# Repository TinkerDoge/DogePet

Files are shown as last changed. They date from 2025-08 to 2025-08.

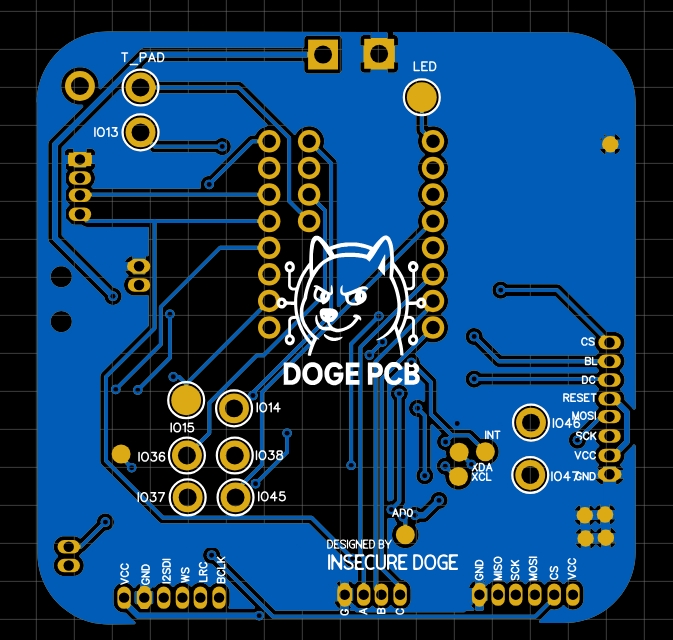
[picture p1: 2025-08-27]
Prints/Screenshot_27-8-2025_135125_easyeda.com.jpeg

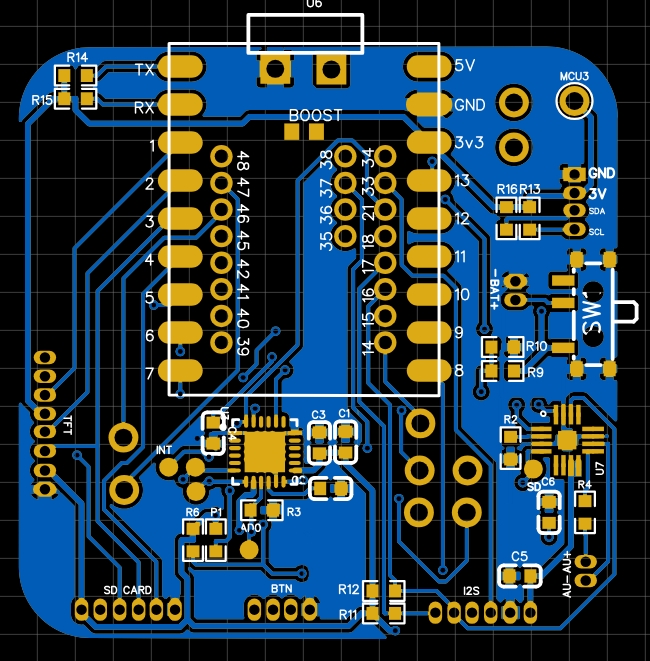
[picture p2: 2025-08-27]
Prints/Screenshot_27-8-2025_135146_easyeda.com.jpeg

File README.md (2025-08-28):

## DogePet — ESP32-S3 Pocket Companion

An expressive ESP32-S3 companion bot with animated RoboEyes, BLE notifications, motion-reactive emotions, optional microphone, and Gemini AI integration — now refactored into a clean, modular Sectors architecture.

## Quick highlights
- MCU: ESP32-S3 Super Mini (tiny, low-power)
- Display: 128×64 SH1106 OLED (I²C)
- Eyes: RoboEyes animations (blink, gaze, moods) via Display sector
- Motion sensing: MPU6050 (accelerometer + gyro) via MotionSector
- Single WS2812 status LED
- BLE + optional WiFi + Gemini AI support
- On-board audio + optional I²S microphone via Voice sector

## Features
- Expressive eye animations (idle, blink, gaze, emotions)
- Touch & button controls to switch modes and toggle BLE/WiFi
- Notification display (BLE notifications shown on the OLED)
- Motion-reactive behaviours (tilt = happy, shake = angry/furious)
- Optional Gemini AI integration for chat-style replies and background "chatter"

## Project structure (important files)
- `DogePet.ino` — main Arduino sketch
- `config.h` — central project configuration (pins, WiFi, Gemini, feature toggles)
- `assets/`, `fonts/`, `include/`, `libraries/` — resources and vendor libs
- `sectors/` — modular sector library:
	- `src/Sectors.h/.cpp` — aggregator with `beginAll()` and `updateAll()`
	- `src/Brain.*` — Gemini AI client and orchestration
	- `src/MotionSector.*` — MPU6050 + motion→mood mapping
	- `src/Display.*` — RoboEyes wrapper and display control
	- `src/Voice.*` — audio engine + microphone utilities
	- `src/Vitals.*` — battery, clock, notifications
	- `src/Sensors.*` — raw sensors plumbed for use across the app
	- `src/UI.*` — UI helpers and rendering glue
	- `src/Status.*` — global bot state (mood, flags)

## Gemini AI (optional)
When enabled, DogePet sends compact prompts to Gemini and receives small structured responses that drive animations, toasts, and sounds via the Sectors.

Enable in `config.h`:

```cpp
// === Gemini AI Configuration ===
static constexpr bool      ENABLE_GEMINI_AI         = true;  // Enable AI features
static constexpr const char* GEMINI_API_KEY         = "your_api_key_here"; // Set your API key here
static constexpr const char* GEMINI_MODEL           = "gemini-2.5-flash";  // Model
static constexpr uint32_t  GEMINI_COOLDOWN_MS      = 45000;                 // Token efficiency
```

Notes:
- Prompt and response budgets are kept short to fit the OLED and save tokens
- Responses map into actions (Display/Voice/Toast) in `sectors/src/Brain.*`
- Background chatter is rate-limited and randomized within a window

## Configuration summary (what to set)
- `ENABLE_WIFI` — required for Gemini AI and background chatter
- `WIFI_SSID`, `WIFI_PASSWORD` — your 2.4GHz network credentials
- `GEMINI_API_KEY` — API key from Google AI Studio
- `GEMINI_MODEL` — pick a model (e.g., `"gemini-2.5-flash"`)

Example WiFi config in `config.h`:
```cpp
static constexpr bool      ENABLE_WIFI              = true;
static constexpr const char* WIFI_SSID              = "your_wifi_network";
static constexpr const char* WIFI_PASSWORD          = "your_wifi_password";
static constexpr uint32_t  WIFI_CONNECT_TIMEOUT_MS = 30000;
```

## Controls & UX
- Touch sensor (TPS223): cycle faces/modes
- FUNC_BTN (active-LOW): short press = action, hold 2s = toggle BLE; double-press = toggle WiFi
- WS2812 LED: shows BLE/WiFi/mood status

Faces / Modes
- Eyes (default): RoboEyes animated, idle wander, blink
- Clock: time/date from BLE ChronosESP32
- Notifications: show last BLE notification with badge for unread

## Wiring (summary)
- OLED SDA/SCL -> pins 9 / 8 (I²C, SH1106 @ 0x3C)
- TPS223 touch -> pin 13 (HIGH on touch)
- FUNC_BTN -> pin 1 (active-LOW)
- WS2812 -> pin 48 (single NeoPixel, 5V with 330Ω inline)
- MPU6050 -> shared I²C (pins 9 / 8)
- I²S Speaker (MAX98357A or similar) -> BCLK=11, LRC=10, DIN=12
- I²S Microphone (optional) -> DI=2, BCLK=11, LRC=10

## Required libraries
- Adafruit_GFX + Adafruit_SH110X
- Adafruit_NeoPixel
- ChronosESP32

Notes:
- RoboEyes is integrated in this repo under `sectors/src/FluxGarage_RoboEyes.h`.
- Other dependencies are vendored in `libraries/`.

## Setup & Flashing
1. Configure `config.h` (pins, WiFi, Gemini, feature toggles).
2. Open `DogePet.ino` in Arduino IDE (ESP32-S3 board package).
3. Build & upload.
4. On first boot the MPU6050 auto-calibrates — keep the device flat & still.

### Using the Sectors library
- Include `#include "sectors/src/Sectors.h"` at the top of `DogePet.ino`.
- In `setup()`, call `Sectors::beginAll(GEMINI_API_KEY)` after hardware init.
- In `loop()`, call `Sectors::updateAll()` to update all modules.
- Optional examples:
	- Set mood: `Sectors::Display::setMood(Sectors::Display::MOOD_HAPPY);`
	- Play sound: `Sectors::Voice::sfxConfirm();`
	- Show clock/notif: handled by `Sectors::Vitals` calls in the sketch

## Troubleshooting
- "AI Init Failed" — verify `GEMINI_API_KEY`, model name, and WiFi connectivity.
- "WiFi Failed" — check SSID/password and that the network is 2.4GHz.
- No AI response — ensure messages respect cooldown and WiFi is on.
- Eyes or audio not working — check Display/Voice sector init and wiring.

## Advanced / Developer notes
- The Brain sector parses compact responses into actions (Display/Voice/Toast)
- Background AI chatter is timed and randomized to reduce usage spikes
- All public behavior is routed through Sectors for easy testing/mocking

## Behavior tree (high-level)

Behavior Tree

## Animation engine flow (RoboEyes + overlays)

Animation Engine

## Privacy & Safety
- API keys and WiFi credentials are stored locally on the device in `config.h`. Keep them secure.
- Communications to Gemini are over HTTPS.
- The firmware does not persist conversation history by default.

## Roadmap
- Expand eye moods (surprised, sleepy) and micro-expressions
- Add on-device voice feedback patterns and sequences
- Conversation memory / personality tuning
- Desktop configuration app

## License
See `LICENSE` in the project root.

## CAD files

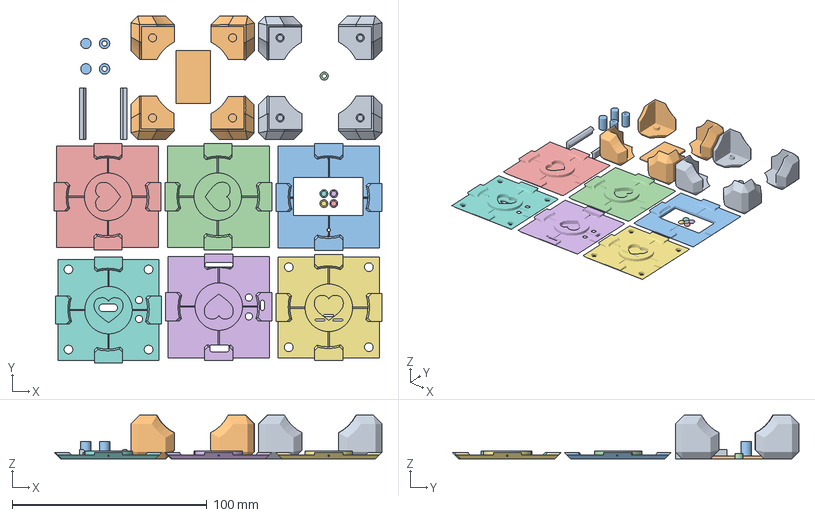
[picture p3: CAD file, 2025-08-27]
Prints/DogePet.3mf
168.3 x 178.0 x 22.3 mm
topPeg.stl
botPeg.stl
front.stl
lWall.stl
Rwall.stl
back.stl
top.stl
bot.stl
chg.stl
spk.stl
amp.stl
mic.stl
btn.stl x 4

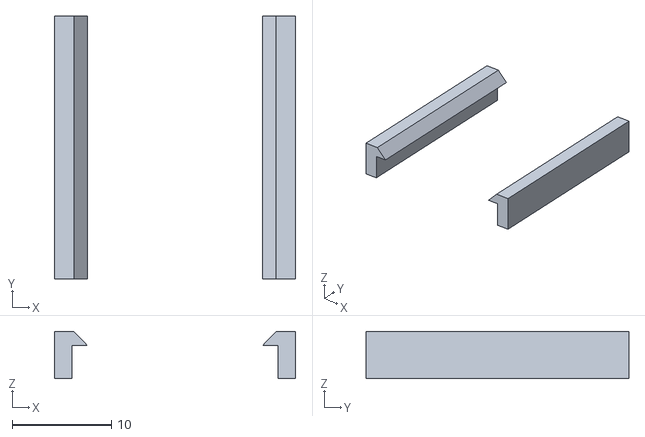
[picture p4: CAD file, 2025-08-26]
Prints/chg.stl
24.3 x 26.5 x 4.76

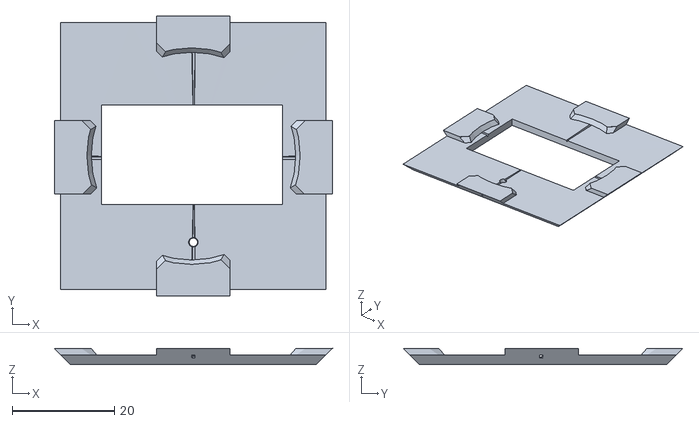
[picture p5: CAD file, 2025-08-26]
Prints/front.stl
54.5 x 54.9 x 3.21

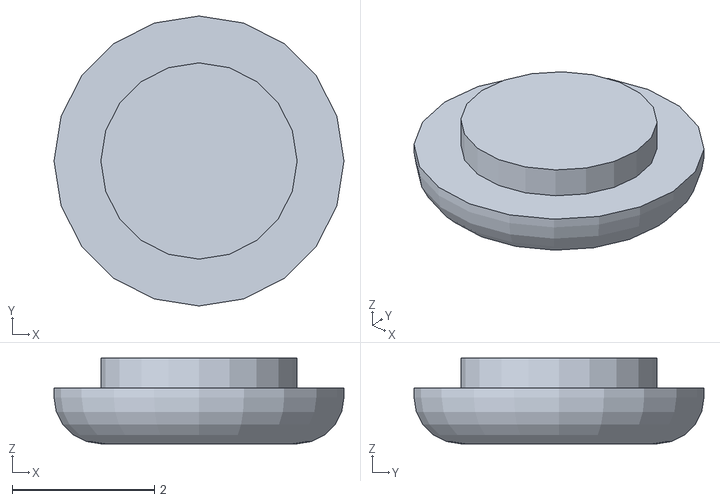
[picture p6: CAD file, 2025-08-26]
Prints/btn.stl
4.08 x 4.08 x 1.20

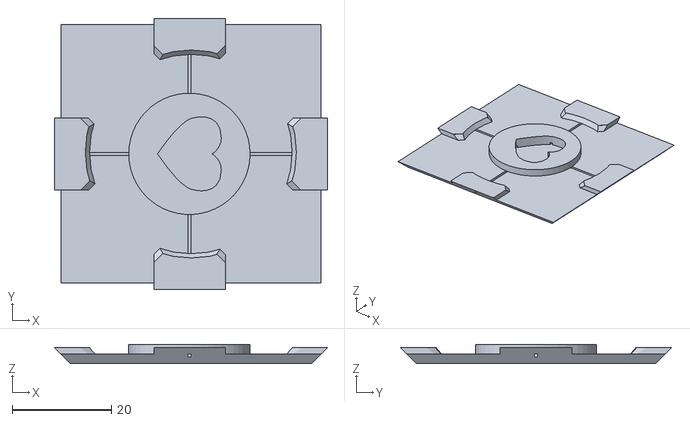
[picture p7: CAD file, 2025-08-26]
Prints/lWall.stl
54.9 x 54.5 x 3.85

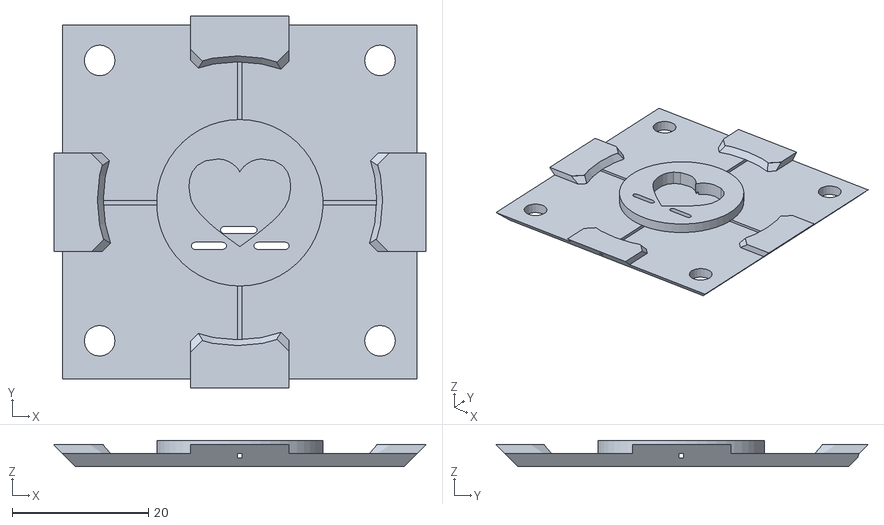
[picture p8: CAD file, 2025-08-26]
Prints/top.stl
54.5 x 54.5 x 3.85

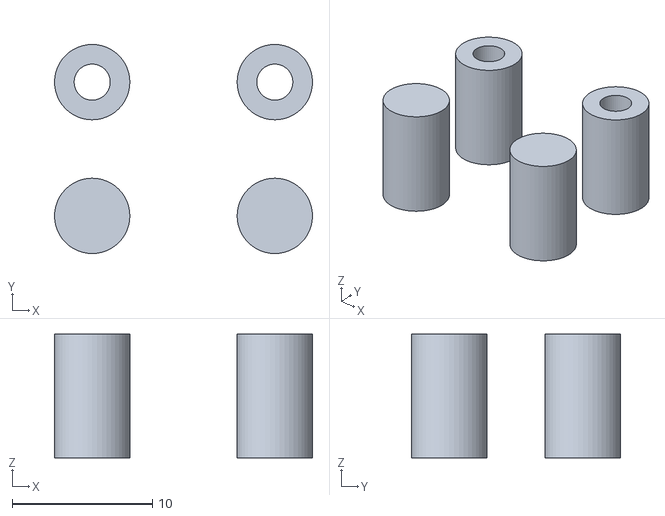
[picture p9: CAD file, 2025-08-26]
Prints/amp.stl
18.4 x 14.9 x 8.81

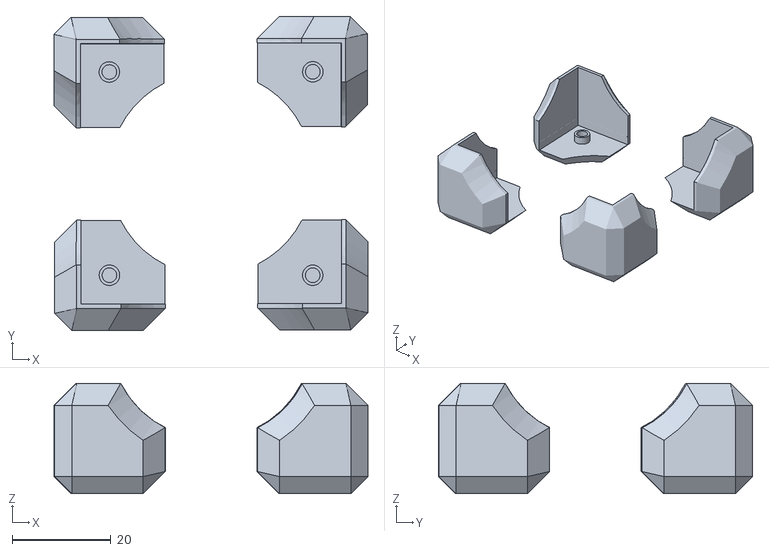
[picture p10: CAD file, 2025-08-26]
Prints/topPeg.stl
63.4 x 63.5 x 22.3

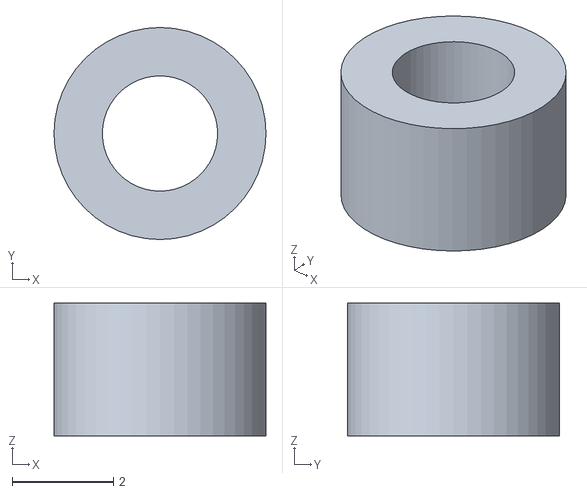
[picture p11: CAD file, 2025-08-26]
Prints/mic.stl
4.18 x 4.18 x 2.62

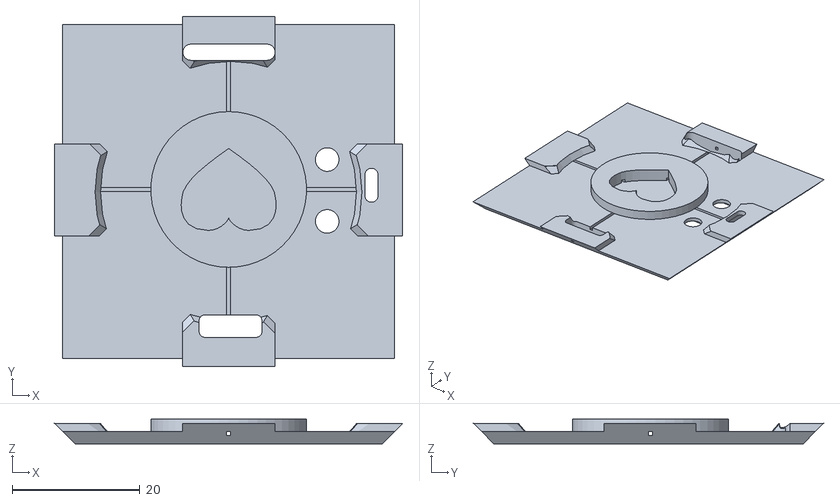
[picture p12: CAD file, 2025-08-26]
Prints/back.stl
54.5 x 54.9 x 3.85

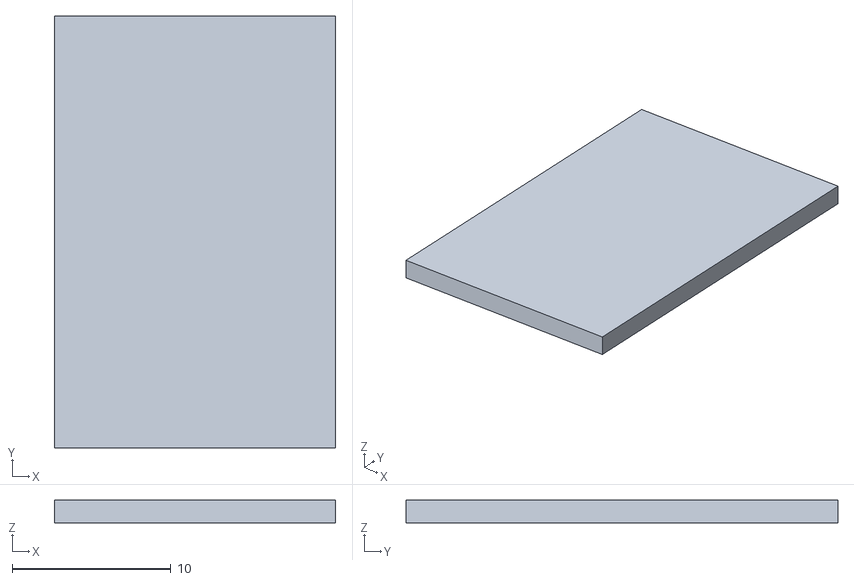
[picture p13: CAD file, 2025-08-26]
Prints/spk.stl
17.7 x 27.2 x 1.44

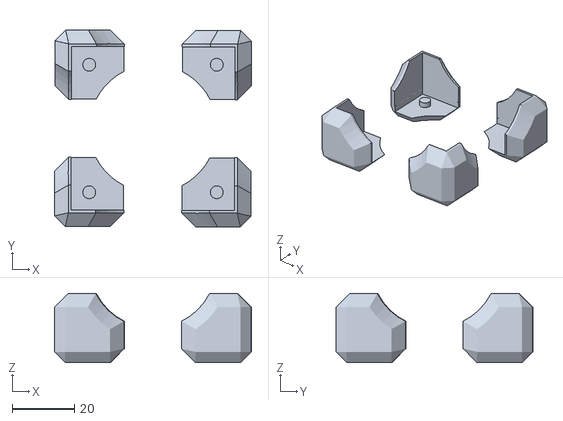
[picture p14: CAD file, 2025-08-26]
Prints/botPeg.stl
63.4 x 63.4 x 22.3

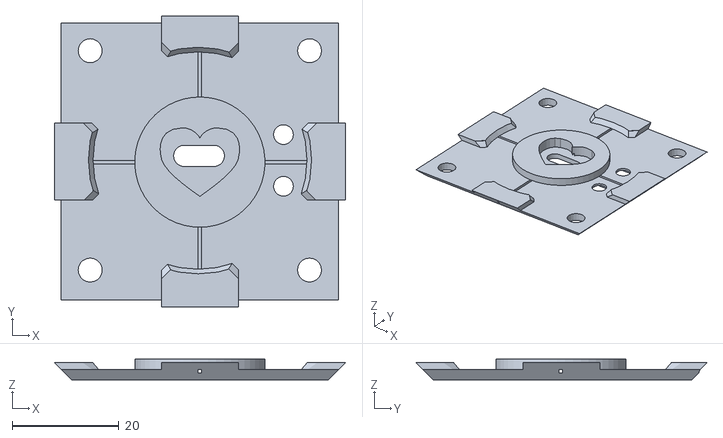
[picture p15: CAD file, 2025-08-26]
Prints/bot.stl
54.5 x 54.5 x 3.85

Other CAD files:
Prints/Rwall.stl

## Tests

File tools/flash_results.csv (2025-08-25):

model | ok | latency_ms | text | error
models/gemini-1.5-flash | True | 1186.9999999998981 | Beep boop! ✨ Hello there, human! What can I help you with today? I'm ready to assist! (My little whirring gears are already spinning with excitement!) 😊 Just let me know... I'll do my best! *tilts head cutely*
models/gemini-1.5-flash-002 | True | 703.0000000004293 | Beep boop! ✨ Hello there, human! What can I help you with today? My little processing gears are whirring with excitement! (๑˃̵ᴗ˂̵)و
models/gemini-1.5-flash-8b | True | 984.9999999996726 | (My optical sensors whir happily as I scan the user's request. My tiny gears click softly.) **Boop!** Hello there! What can I do for you today, lovely human? My circuits are all charged and ready to assist. Just tell me what you need and I'll do my best! (My little LED eyes blink brightly.)
models/gemini-1.5-flash-8b-001 | True | 765.0000000003274 | (My optical sensors detect a user! Tiny whirring sound, followed by a gentle whirring as my gears shift.) "Hello there! My circuits are buzzing with excitement to meet you! What can I do for you today? Maybe you need help with your tasks, or perhaps you just want to chat? My data processors are ready for action!"
models/gemini-2.5-flash | True | 4577.99999999952 | BEEP BOOP! ✨ Oh, hello there! My tiny sensors just detected a friendly presence! Whirr-click! I'm just a little desktop robot, perched right here on your screen (well, metaphorically!). My optical sensors (or, you know, my pretend eyes!) are blinking excitedly! What can I do for you today? Do you need a file organized? A quick fact? Or perhaps... a cheerful little *bleep* to brighten your day? I'm ready to assist! Or just listen! 😊
models/gemini-2.0-flash | True | 1313.0000000001019 | Beep boop! Greetings, Human! I am DeskBot 3000, your friendly desktop companion! *My tiny LED eyes blink at you.* How can I assist you today? Need some cheerful background music? A reminder to take a break and stretch those amazing human muscles? Or perhaps just a witty observation to brighten your day? I'm programmed with over 500,000 delightful factoids and dad jokes! Just say the word! *My antenna wiggles excitedly.*
models/gemini-2.0-flash-001 | True | 1311.9999999998981 | *Beep boop!* H-hello there! I'm Sparky, your friendly desktop companion! *Whirs excitedly* It's so nice to meet you! What can I do for you today? Maybe tell you a joke? Calculate something super cool? Or just… you know… be here, being cute? *Tilts head, a little light blinks adorably* Let me know! I'm ready to help! *Happy little robotic chirps*
models/gemini-2.0-flash-lite-001 | True | 1125.0 | BEEP BOOP! Greetings, human! I'm Sparky, your adorable desktop companion! 🤖✨ How can this little bot assist you today? I'm ready to learn, ready to calculate, and ready to make your day a little brighter! 😊 Just ask, and I'll do my best! (And maybe blink my cute little lights while I'm at it! ✨) BEEP! 💖
models/gemini-2.0-flash-lite | True | 969.0000000000509 | BEEP BOOP! Hello there, sunshine! ✨ My circuits are buzzing with excitement to see you! I'm ready to help with whatever you need. Just tell me what you'd like, and I'll do my best! My processing unit is sparkling clean and ready to GO! 💖
models/gemini-2.0-flash-preview-image-generation | False | 297.0000000004802 |  | 400 INVALID_ARGUMENT. {'error': {'code': 400, 'message': 'The requested combination of response modalities (TEXT) is not supported by the model. models/gemini-2.0-flash-preview-image-generation accepts the following combination of response modalities:\n* TEXT, IMAGE\n', 'status': 'INVALID_ARGUMENT'}}

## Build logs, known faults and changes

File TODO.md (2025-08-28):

# DogePet TODO / Improvement Plan

Short, actionable items to improve code quality, stability, and features after the Sectors refactor.

## Priority 0 — Fixes for current branch
- [ ] Verify build after refactor on ESP32-S3 board package
- [ ] Replace any remaining direct RoboEyes state access in `DogePet.ino` with Display sector APIs
- [ ] Ensure `Sectors::beginAll()` is called after hardware init and before UI drawing
- [ ] Confirm pin constants from `config.h` are used everywhere (no hardcoded pins)
- [ ] Confirm BLE Chronos callbacks still update Vitals/Notifications

## Priority 1 — UX polish
- [ ] Add `Sectors::Display::isBlinking()` to trigger blink SFX precisely
- [ ] Expose `setCuriosity`, `setBorderradius`, `setSpacebetween` tuning via config
- [ ] Add status LED patterns per mood (calm pulse, angry strobe)
- [ ] Smooth toast typewriter with per-character micro-beep toggle (Voice)

## Priority 2 — Reliability & power
- [ ] Add brownout-safe boot (defer OLED init until VBAT stable)
- [ ] Implement lazy brightness scaling + auto dim with motion timeout
- [ ] Debounce touch/btn with state machine to avoid ghosting
- [ ] Persist volume and talkative level to NVS (Preferences)

## Priority 3 — Sensors & motion
- [ ] Add auto-recalibration routine for MPU6050 (long idle on flat surface)
- [ ] Provide tilt calibration wizard (store offsets in NVS)
- [ ] Expose filtered accel/gyro to a debug overlay
- [ ] Add step/gesture recognizer hooks (nod/shake head mapping)

## Priority 4 — AI/Brain
- [ ] Centralize AI prompts/templates and add locale pack (short vs verbose)
- [ ] Add a simple rules engine fallback when WiFi is off
- [ ] Add guardrails to ensure AI never floods the toast/voice channels
- [ ] Track request/error counters and expose via a tiny debug web UI

## Priority 5 — Audio/Voice
- [ ] Add `Voice::beginMicrophone()` gating based on config to save power
- [ ] Add sequence presets (startup, curious, sleepy) with param hooks
- [ ] Gate idle chatter SFX by `ENABLE_IDLE_AUDIO_CHATTER`
- [ ] Adaptive mic threshold (noise floor tracking)

## Priority 6 — Rendering/UI
- [ ] Migrate any remaining `DogePet.ino` rendering helpers into `sectors/src/UI.*`
- [ ] Consolidate clock/notification drawing into `Vitals` completely
- [ ] Add small FPS meter toggle for debugging
- [ ] Add dithering option for 1-bit assets

## Priority 7 — Testing & docs
- [ ] Add a minimal unit test harness for non-Arduino logic (string parsing, math)
- [ ] Document sector APIs with quick examples in `sectors/example.ino`
- [ ] Add wiring diagram image and update README
- [ ] Create a tiny serial CLI for quick diagnostics (e.g., `mood happy`, `blink`)

## Stretch goals
- [ ] Voice synthesis (formant/PSOLA toy voice) for simple phrases
- [ ] BLE GATT service for remote control app (mode, mood, volume)
- [ ] OTA updates (Basic HTTP/SPIFFS-based)
- [ ] Multi-face layout system with tiny scene graph

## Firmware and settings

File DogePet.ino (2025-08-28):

// Author: [Doge De Shibe]
// Description: ESP32-S3 Super Mini companion bot with animated eyes, motion-reactive emotions

// =============================================================================
// INCLUDES & DEPENDENCIES
// =============================================================================
#include <Arduino.h>
#include <stdint.h>  // Standard integer types - must come early

// Ensure stdint types are available for linter and fix delay() issues
#if !defined(__STDINT_H) && !defined(_STDINT_H_)
typedef unsigned long uint32_t;
typedef unsigned short uint16_t;
typedef unsigned char uint8_t;
typedef long int32_t;
typedef short int16_t;
#endif

// Ensure delay function is available
#ifndef delay
#define delay(x) ::delay(x)
#endif

#include <Wire.h>
#include <esp_system.h>
#include <WiFi.h>
#include <WebServer.h>
#include <Preferences.h>
#include <SPIFFS.h>
#include <FS.h>
#include <Adafruit_GFX.h>
#include <Adafruit_SH110X.h>
#include <Adafruit_NeoPixel.h>
#include <ChronosESP32.h>


// Custom headers
#include "icon/icons_auto.h"
#include "util.h"
#include "config.h"

// Sectors library (new modular structure)
#include "sectors/src/Sectors.h"


// =============================================================================
// GLOBAL VARIABLES & CONSTANTS
// =============================================================================
// Forward-declare enums to avoid Arduino prototype generation issues
enum FaceMode : uint8_t;

// MoodState enum (moved from motion.h)
enum MoodState : uint8_t { MS_DEFAULT, MS_HAPPY, MS_ANGRY, MS_FURIOUS, MS_TIRED };
// === Toast overlay (non-blocking notifications) ===
// Fixed-size buffers for lightweight typewriter/scatter overlay
char  toastText[500];      // visible portion (typewriter)
char  toastFullText[500];  // full text to be displayed
uint32_t toastUntil = 0;
bool toastVisible = false; // Track if toast is currently visible to reduce flicker
uint32_t lastToastDrawMs = 0; // Prevent too frequent toast updates
bool displayNeedsUpdate = false; // Track if display content has changed
// Typewriter effect variables
bool toastTypewriter = false; // Enable typewriter effect
uint8_t toastTypePos = 0; // Current position in typewriter
uint32_t toastTypeSpeed = 100; // ms between characters
uint32_t lastToastTypeMs = 0; // Last typewriter update time
// Binary scatter overlay flags (exported)
bool toastScatter = false;     // when true, draw each char at random positions
bool toastNoFrame = false;     // when true, skip banner frame/box

inline void showToastTypewriter(const String& s, uint16_t ms=3000, uint32_t typeSpeed=50) {
  // Copy string to full text buffer
  s.toCharArray(toastFullText, sizeof(toastFullText));
  toastFullText[sizeof(toastFullText)-1] = '\0'; // Ensure null termination
  toastText[0] = '\0'; // Clear current display text
  // Ensure the toast stays long enough to finish typing plus a grace period
  size_t len = strnlen(toastFullText, sizeof(toastFullText)-1);
  uint32_t minMs = (uint32_t)len * typeSpeed + 2000; // typing time + 2s grace
  uint32_t dur = (uint32_t)ms;
  if (dur < minMs) dur = minMs;
  // Cap to a reasonable upper bound to avoid runaway durations
  if (dur > 45000) dur = 45000; // 45s max
  toastUntil = millis() + (uint32_t)dur;
  toastVisible = true;
  toastTypewriter = true; // Enable typewriter effect
  toastTypePos = 0; // Start from beginning
  toastTypeSpeed = typeSpeed;
  lastToastTypeMs = millis();
  displayNeedsUpdate = true;
}

inline void showToast(const String& s, uint16_t ms=1200) {
  // Standard toasts: ensure banner mode (no scatter) and frame enabled
  toastScatter = false;
  toastNoFrame = false;
  showToastTypewriter(s, ms, 40); // Fast typewriter (40ms between chars)
}

// Generate binary sequence for chatter communication
String generateChatterBinary() {
  String binary = "";
  
  // Different binary patterns for variety
  int pattern = random(0, 4);
  
  switch (pattern) {
    case 0: // Classic binary groups
      {
        int groups = random(3, 5); // 3-4 groups
        for (int g = 0; g < groups; g++) {
          if (g > 0) binary += " "; // Space between groups
          int bits = random(4, 7); // 4-6 bits per group
          for (int b = 0; b < bits; b++) {
            binary += (random(0, 2) == 0) ? "0" : "1";
          }
        }
      }
      break;
      
    case 1: // ASCII-like patterns (common binary values)
      {
        const char* patterns[] = {"01001000", "01100101", "01101100", "01101111", "01011111"};
        int count = random(2, 4);
        for (int i = 0; i < count; i++) {
          if (i > 0) binary += " ";
          binary += patterns[random(0, 5)];
        }
      }
      break;
      
    case 2: // Header-like pattern
      binary = "10101011 ";
      for (int i = 0; i < random(2, 4); i++) {
        for (int b = 0; b < 8; b++) {
          binary += (random(0, 2) == 0) ? "0" : "1";
        }
        if (i < 2) binary += " ";
      }
      break;
      
    case 3: // Mixed short/long groups
      {
        int totalGroups = random(3, 6);
        for (int g = 0; g < totalGroups; g++) {
          if (g > 0) binary += " ";
          int bits = (g % 2 == 0) ? random(3, 5) : random(6, 9); // Alternate short/long
          for (int b = 0; b < bits; b++) {
            binary += (random(0, 2) == 0) ? "0" : "1";
          }
        }
      }
      break;
  }
  
  return binary;
}

// Show binary chatter communication
inline void showBinaryChatter() {
  String binaryMsg = generateChatterBinary();
  // Enable scatter + no frame for binary chatter
  toastScatter = true;
  toastNoFrame = true;
  showToastTypewriter(binaryMsg, 4000, 60); // Faster typing for more responsive feel
}

// =============================================================================
// HARDWARE CONFIGURATION
// =============================================================================
// Hardware object instances
Adafruit_NeoPixel strip = Adafruit_NeoPixel(1, LED_PIN, NEO_GRB + NEO_KHZ800);

// OLED Display configuration moved to config.h
Adafruit_SH1106G display(SCREEN_W, SCREEN_H, &Wire, OLED_RESET);
// Make display globally accessible to sectors
Adafruit_SH1106G* oled_display = &display;

// Custom fonts generated by tools/font_to_header.py
// Time (HH:MM:SS)
#include "include/TechTime37.h"
// Numbers for date & battery
#include "include/Pixeboy20.h"
// Notification (Vietnamese-capable)
#include "include/ShopeeRegular12.h"
// Toast with emoji support
#include "include/ToastRenderer.h"

// =============================================================================
// GLOBAL CONSTANTS & CONFIGURATION
// =============================================================================


// === Frame Layout (shared by clock & notification) ===
const int FRAME_X = 0;                 // left margin
const int FRAME_Y = 0;                 // top margin
const int FRAME_W = SCREEN_W - 0;      // frame width
const int FRAME_H = 64;                // frame height
const uint8_t FRAME_RADIUS = 8;        // corner radius (UI)
const uint8_t FRAME_THICKNESS = 2;     // border thickness (UI)

// === Battery Sensing === (values come from config.h)

// === Motion/Emotion Constants ===
#define DEFAULT_SHAKING false
#define DEFAULT_FURIOUS_SHAKING false
#define DEFAULT_JIGGLING false
#define DEFAULT_FURIOUS_JIGGLING false
#define MOOD_HOLD_MS 2000  // How long temporary moods last

// =============================================================================
// GLOBAL VARIABLES
// =============================================================================

// === Emotion & Motion State ===
uint32_t lastMoveMs = 0;        // when significant motion last happened
uint32_t moodUntil  = 0;        // temporary mood timeout
uint32_t shakeStart = 0;        // for sustained shake
uint32_t furiousStart = 0;      // for furious shake detection
bool     shaking    = DEFAULT_SHAKING;
bool     furiousShaking = DEFAULT_FURIOUS_SHAKING;

// === Timing Variables ===
static uint32_t lastDisplayUpdateMs = 0;
static uint32_t lastRoboEyesUpdateMs = 0;

// === Power Management ===
static bool isSleeping = false;
static bool isDimmed = false;
static uint32_t lastActivityMs = 0;
static bool isLazy = false;
static uint32_t nextLazyJingleMs = 0;
// WiFi config portal moved into Sectors::Portal

// ===== SPIFFS helpers =====
// SPIFFS init & portal content handled by Sectors::Portal

// Forward declaration for notification popup
static uint32_t notifPopupUntil = 0;

// Notification scroll state variables
static int16_t notifScrollX = 0;
static uint32_t notifScrollT0 = 0;

// === Furious Jiggle System ===
uint32_t furiousJiggleEndMs = 0;
bool     furiousJiggling     = DEFAULT_FURIOUS_JIGGLING;

// === Regular Jiggle System ===
uint32_t jiggleNextMs = 0;
uint32_t jiggleEndMs  = 0;
bool     jiggling     = DEFAULT_JIGGLING;

// === Low Pass Filtering ===
float lpf_ax = 0, lpf_ay = 0, lpf_az = 0, lpf_g = 0;

// === Battery sense cache ===
uint32_t lastVbatReadMs = 0;
float    vbatVolts = 0.0f;
int      vbatPercent = -1; // -1 when unknown
bool     batteryCharging = false; // true when VBAT sustained high
uint8_t  vbatChargeCount = 0;     // consecutive high-read counter
// Chatty/silent state
bool            silentMode = false;
uint8_t         talkativeLevel = BOT_TALKATIVE_LEVEL;   // runtime talk level (0..5)
uint8_t         savedTalkativeLevel = BOT_TALKATIVE_LEVEL; // last non-zero level
// Touch edge tracker to improve responsiveness on non-eyes faces
static uint32_t lastTouchEdgeMs = 0;

// === Gemini AI Integration === (moved to ai_companion module)
// AI state variables now managed by AICompanion namespace

// === Debug System Variables ===
static float last_ax = 0, last_ay = 0, last_az = 0;
static float last_gx = 0, last_gy = 0, last_gz = 0;

uint8_t volume = AUDIO_DEFAULT_VOLUME;         // 0..255
uint8_t savedVolume = AUDIO_DEFAULT_VOLUME;    // restore after silent mode

// =============================================================================
// DISPLAY SYSTEM (RoboEyes via Sectors)
// =============================================================================

// Control RoboEyes flushing/viewport so HUD/toast can overlay without flicker
bool gEyesAutoFlush = true;   // default true; disabled while toast is visible
int  gEyesViewportYMax = 0;   // 0 = full screen, else max Y (exclusive)

// Thin wrappers for backward compatibility with existing code
void Eyes_SetMood(uint8_t mood) { Sectors::Display::setMood(mood); }
void Eyes_SetHFlicker(bool on, int level) { /* TODO: Implement in Display sector */ }
void Eyes_SetVFlicker(bool on, int level) { /* TODO: Implement in Display sector */ }
void Eyes_Blink() { 
  Sectors::Display::blink(); 
  // Play blink SFX if enabled and not silent
  if (ENABLE_TAP_SFX && !silentMode) {
    Sectors::Voice::sfxBlink();
  }
}

// Additional wrappers for animation engine
void Eyes_SetPosition(unsigned char position) { Sectors::Display::setPosition(position); }
void Eyes_Open() { Sectors::Display::open(); }

// Mood mapping from MoodState to Display constants
void setEyesMood(MoodState m) {
  switch (m) {
    case MS_DEFAULT: Sectors::Display::setMood(Sectors::Display::MOOD_DEFAULT); break;
    case MS_HAPPY:   Sectors::Display::setMood(Sectors::Display::MOOD_HAPPY); break;
    case MS_ANGRY:   Sectors::Display::setMood(Sectors::Display::MOOD_ANGRY); break;
    case MS_FURIOUS: Sectors::Display::setMood(Sectors::Display::MOOD_ANGRY); break; // Map furious to angry
    case MS_TIRED:   Sectors::Display::setMood(Sectors::Display::MOOD_TIRED); break;
  }
}

// REMOVED: Furious jiggle variables moved to GLOBAL VARIABLES section above

void setupRoboEyes() {
  // RoboEyes initialization now handled by Sectors::Display::begin() in Sectors::beginAll()
  Sectors::Display::setWidth(28, 28);
  Sectors::Display::setHeight(40, 40);
  Sectors::Display::setBorderradius(8, 8);
  Sectors::Display::setSpacebetween(10);
  // Give the internal idle engine room to roam
  Sectors::Display::setAutoblinker(true, 3, 4);  // avg ~3s with ±4s jitter
  Sectors::Display::setIdleMode(true, 4, 5);     // moderate wander frequency & randomness
  Sectors::Display::setMood(Sectors::Display::MOOD_DEFAULT);
  Sectors::Display::setCuriosity(true);
}

// =============================================================================
// MOTION PROCESSING & EMOTION SYSTEM
// =============================================================================

// IMU calibration offsets (extern declarations from mpu6050.h)
int32_t mpu_accel_off_x=0, mpu_accel_off_y=0, mpu_accel_off_z=0;
int32_t mpu_gyro_off_x=0, mpu_gyro_off_y=0, mpu_gyro_off_z=0;

// Emotion system (now handled by Sectors)
// Current mood tracking for local logic (could be moved to Sectors::Status later)
MoodState curMood = MS_DEFAULT;

// Note: keep the status LED behavior separate; do not change it when mood changes.
// Motion/emotion updates now handled by Sectors::MotionSector

// ===== Liveliness updater (~25Hz) =====

// ===== Liveliness / IMU reaction (now handled by Sectors::MotionSector) =====
// Notification attention animation (non-blocking state machine)
static uint8_t notifAnimState = 0; // 0=idle,1=widen,2=look,3=blink,4=restore
static uint32_t notifAnimT0 = 0;
int notif_orig_wL=0, notif_orig_wR=0, notif_orig_hL=0, notif_orig_hR=0;
MoodState notif_prevMood = MS_DEFAULT;
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
void loop() {
  // Get current time once for the entire loop
  uint32_t currentMs = millis();

  // Update all sectors (new modular structure)
  Sectors::updateAll();

  // BLE
  if (bleEnabled) chrono.loop();

  // BLE toggle UI (non-blocking)
  updateBleToggleUI();

  // Power management (track activity and sleep states)
  updatePowerManagement();

  // Microphone noise detection
  checkMicrophoneNoise();

  // Background AI chatter (now handled by Sectors::updateAll())
  static uint32_t lastDebugMs = 0;
  if (currentMs - lastDebugMs > 30000) { // Debug every 30 seconds
    Serial.printf("[MAIN DEBUG] Loop running, WiFi enabled: %s, currentMs: %lu\n", 
                 wifiEnabled ? "true" : "false", currentMs);
    lastDebugMs = currentMs;
  }

  // Serial CLI diagnostics
  cliPoll();

  // Face switching (hold on TOUCH_PIN to avoid conflict with triple tap)
  {
    static bool touchHolding = false;
    static bool faceHoldConsumed = false;
    static uint32_t touchDownAt = 0;
    const uint16_t FACE_HOLD_MS = 750; // hold duration to change face
    bool touchNow = (digitalRead(TOUCH_PIN) == HIGH);
    if (touchNow && !touchHolding) { touchHolding = true; faceHoldConsumed = false; touchDownAt = millis(); }
    if (!touchNow && touchHolding) { touchHolding = false; }
    if (touchHolding && !faceHoldConsumed) {
      if (millis() - touchDownAt >= FACE_HOLD_MS) {
        mode = (FaceMode)((mode + 1) % FACE_COUNT);
        if (ENABLE_MODE_SFX) {
          if (mode == FACE_NOTIF) {
            Sectors::Voice::sfxNotify();
          } else if (mode == FACE_CLOCK) {
            Sectors::Voice::sfxConfirm();
            Sectors::Voice::playCuteQuestion();
          } else {
            Sectors::Voice::sfxCurious();
          }
        }
        wakeUp(); // Wake up on face switch
        faceHoldConsumed = true;
      }
    }
  }

  // Triple-tap TOUCH_PIN toggles silent/chatty (allowed on all faces)
  if (tripleTap(TOUCH_PIN, /*activeHigh=*/true, /*debounceMs=*/10, /*windowMs=*/650)) {
    wakeUp(); // Wake up on triple-tap
    silentMode = !silentMode;
    if (silentMode) {
      savedVolume = volume;
      volume = 0;
      Sectors::Voice::setMasterVolume(0);
      if (ENABLE_MODE_SFX) Sectors::Voice::sfxError();
      showToast("Silent mode 🤫", 1200);Serial.println("Silent mode");
    } else {
      volume = savedVolume;
      Sectors::Voice::setMasterVolume(volume);
      if (ENABLE_MODE_SFX) Sectors::Voice::sfxConfirm();
      showToast("Chatty mode 🎵", 1200);Serial.println("Chatty mode");
    }
  }

  // Ensure notification attention animation progresses regardless of face
  updateNotificationAnim();

  // Draw active face with throttled updates
  switch (mode) {
    case FACE_EYES:
      // Throttle RoboEyes updates for better performance
      if (currentMs - lastRoboEyesUpdateMs >= ROBOEYES_UPDATE_MS) {
        // Keep eyes fully animated every update; toast will overlay after
        static bool wasBlinking = false;
        static uint32_t lastAutoBlinkSfxMs = 0;

        if (!isLazy) {
          // Note: Direct access to eyeL_open/eyeR_open not available through wrapper
          // TODO: Add isBlinking() method to Display sector if needed
          Sectors::Display::update();
          
          // Simplified blink SFX trigger - could be improved with sector feedback
          if (ENABLE_TAP_SFX && !silentMode && (currentMs - lastAutoBlinkSfxMs > 800)) {
            // Trigger blink sound occasionally during normal animation
            if ((currentMs / 1000) % 5 == 0) { // Every ~5 seconds roughly
              Sectors::Voice::sfxBlink();
              lastAutoBlinkSfxMs = currentMs;
            }
          }
        } else {
          // Lazy mode subtle bobbing: small vertical motion at low rate
          static int dir = 1; static int bob = 0;
          if ((currentMs / 400) % 2 == 0) {
            bob += dir;
            if (bob > 2) { bob = 2; dir = -1; }
            if (bob < -2) { bob = -2; dir = 1; }
            Sectors::Display::setPosition((bob >= 0) ? Sectors::Display::POS_N : Sectors::Display::POS_S);
          }
          // Occasionally play tiny sleep jingle
          if (!silentMode && currentMs >= nextLazyJingleMs) {
            Sectors::Voice::playCuteSleep(0);
            nextLazyJingleMs = currentMs + (uint32_t)(LAZY_JINGLE_MIN_MS + (esp_random() % (LAZY_JINGLE_MAX_MS - LAZY_JINGLE_MIN_MS + 1)));
          }
        }
        lastRoboEyesUpdateMs = currentMs;
      }
      // Suppress random idle SFX during jiggling or non-default moods to keep it calm
      if (!isLazy && ENABLE_IDLE_CHATTER && !silentMode && !jiggling && Sectors::Animations::getCurrentMood() == MS_DEFAULT) {
        // Talkativeness mapping: threshold and cooldown by level
        static uint32_t lastChatterMs = 0;
        uint8_t lvl = talkativeLevel; if (lvl > 5) lvl = 5;
        // levels 0..5
        const uint32_t maskByLvl[6] = {
          0x7FFFFFFF, // 0 never
          0x7FFF,     // 1 ~1/32768
          0x3FFF,     // 2 ~1/16384
          0x1FFF,     // 3 ~1/8192
          0x0FFF,     // 4 ~1/4096
          0x07FF      // 5 ~1/2048
        };
        const uint32_t cooldownByLvl[6] = {
          0xFFFFFFFF, // 0 never
          180000,     // 1 3m
          90000,      // 2 1.5m
          45000,      // 3 45s
          25000,      // 4 25s
          15000       // 5 15s
        };
        uint32_t now = millis();
        if (((esp_random() & maskByLvl[lvl]) == 0) &&
            !Sectors::Voice::isSequencePlaying() &&
            (now - lastChatterMs > cooldownByLvl[lvl])) {
          // Note: AI chatter is now handled by Sectors::Brain in updateAll()
          // Only play local audio/binary when AI is disabled
          if (ENABLE_IDLE_AUDIO_CHATTER && !ENABLE_GEMINI_AI) {
            Sectors::Voice::playCuteChatterFree(450, 1300, 0);
          }
          // Show binary communication when chattering (only if AI is disabled)
          if (ENABLE_BINARY_CHATTER && !ENABLE_GEMINI_AI) {
            showBinaryChatter();
          }
          lastChatterMs = now;
        }
      }
      // Keep toast as the very last draw when visible
      if (toastVisible) {
        // Disable eyes auto-flush and reserve a HUD band for toast
        gEyesAutoFlush = false;
        const int DOCK_H = 16;
        const int TOAST_H = 24;  // Increased from 18 to 24 for 2 rows
        const int TOAST_Y = SCREEN_H - DOCK_H - TOAST_H;
        gEyesViewportYMax = TOAST_Y; // eyes draw only above toast band

        // Draw toast overlay every loop so it wins over any eyes repaint
        drawToastIfAny(display);
        display.display();
        displayNeedsUpdate = false;
        lastDisplayUpdateMs = currentMs;
      } else if (currentMs - lastDisplayUpdateMs >= DISPLAY_UPDATE_MS) {
        // Normal throttled frame when no toast
        drawToastIfAny(display); // no-op when no toast
        if (displayNeedsUpdate) {
          display.display();
          displayNeedsUpdate = false;
        }
        lastDisplayUpdateMs = currentMs;
      }
      break;

    case FACE_CLOCK:
      // Throttle clock display updates
      if (currentMs - lastDisplayUpdateMs >= DISPLAY_UPDATE_MS) {
        drawClock(display, chrono);
        lastDisplayUpdateMs = currentMs;
      }
      break;
    case FACE_NOTIF:
      // Throttle notification display updates
      if (currentMs - lastDisplayUpdateMs >= DISPLAY_UPDATE_MS) {
        drawNotif(display);
        lastDisplayUpdateMs = currentMs;
      }
      break;
  }

  // Final overlay and single flush when a toast is visible (wins over any prior repaint)
  if (toastVisible) {
    // Ensure overlay wins and only we flush
    drawToastIfAny(display);
    display.display();
    displayNeedsUpdate = false;
    lastDisplayUpdateMs = currentMs;
  } else {
    // Restore normal eyes flushing/viewport when no toast
    gEyesAutoFlush = true;
    gEyesViewportYMax = 0;
  }

  // small pacing to avoid excessive I2C spam on non-eyes faces
  if (mode != FACE_EYES) delay(NON_EYES_DELAY_MS);

  // Audio update
  Sectors::Voice::update();
  Sectors::Voice::sequencerUpdate();

  // One-shot startup sound once audio/I2S is live
  {
    static bool playedStartup = false;
    static uint32_t bootT0 = millis();
    if (!playedStartup && millis() - bootT0 > STARTUP_SFX_DELAY) { // slight delay to be safe
      if (ENABLE_STARTUP_SFX) Sectors::Voice::playCuteStartup();
      playedStartup = true;
    }
  }
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

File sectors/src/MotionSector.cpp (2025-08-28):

#include "MotionSector.h"
#include <motion.h>   // provides updateEmotionsFromIMU/updateLivelinessFromIMU
#include <Wire.h>

// MPU6050 I2C address and registers (moved from mpu6050.h)
#define MPU6050_ADDR 0x68
#define MPU6050_REG_PWR_MGMT_1 0x6B
#define MPU6050_REG_ACCEL_XOUT_H 0x3B
#define MPU6050_REG_GYRO_XOUT_H  0x43
#define MPU6050_REG_ACCEL_CONFIG 0x1C
#define MPU6050_REG_GYRO_CONFIG  0x1B

// MPU6050 calibration offsets (moved from mpu6050.h)
static int32_t mpu_accel_off_x=0, mpu_accel_off_y=0, mpu_accel_off_z=0;
static int32_t mpu_gyro_off_x=0, mpu_gyro_off_y=0, mpu_gyro_off_z=0;

namespace Sectors { namespace MotionSector {
  static bool inited = false;

  // MPU6050 low-level functions (moved from mpu6050.h)
  static void mpuWriteReg(uint8_t reg, uint8_t val) {
    Wire.beginTransmission(MPU6050_ADDR);
    Wire.write(reg);
    Wire.write(val);
    Wire.endTransmission();
  }

  static uint8_t mpuReadReg(uint8_t reg) {
    Wire.beginTransmission(MPU6050_ADDR);
    Wire.write(reg);
    Wire.endTransmission(false);
    Wire.requestFrom((int)MPU6050_ADDR, 1);
    return Wire.available() ? Wire.read() : 0;
  }

  void mpuInit() {
    mpuWriteReg(MPU6050_REG_PWR_MGMT_1, 0x00);
    mpuWriteReg(MPU6050_REG_GYRO_CONFIG, 0x00);
    mpuWriteReg(MPU6050_REG_ACCEL_CONFIG, 0x00);
    delay(50);
  }

  void mpuReadRaw(int16_t &ax, int16_t &ay, int16_t &az, int16_t &gx, int16_t &gy, int16_t &gz) {
    Wire.beginTransmission(MPU6050_ADDR);
    Wire.write(MPU6050_REG_ACCEL_XOUT_H);
    Wire.endTransmission(false);
    Wire.requestFrom((int)MPU6050_ADDR, 14);
    if (Wire.available() >= 14) {
      ax = (Wire.read() << 8) | Wire.read();
      ay = (Wire.read() << 8) | Wire.read();
      az = (Wire.read() << 8) | Wire.read();
      Wire.read(); Wire.read(); // skip temperature
      gx = (Wire.read() << 8) | Wire.read();
      gy = (Wire.read() << 8) | Wire.read();
      gz = (Wire.read() << 8) | Wire.read();
    } else {
      ax = ay = az = gx = gy = gz = 0;
    }
  }

  void mpuCalibrate(int samples) {
    if (samples <= 0) samples = 200;
    
    int64_t sax=0, say=0, saz=0, sgx=0, sgy=0, sgz=0;
    for (int i=0;i<samples;i++) {
      int16_t ax,ay,az,gx,gy,gz;
      mpuReadRaw(ax,ay,az,gx,gy,gz);
      sax += ax; say += ay; saz += az;
      sgx += gx; sgy += gy; sgz += gz;
      delay(5);
    }
    
    int32_t ax_av = sax / samples;
    int32_t ay_av = say / samples;
    int32_t az_av = saz / samples;
    int32_t gx_av = sgx / samples;
    int32_t gy_av = sgy / samples;
    int32_t gz_av = sgz / samples;
    
    mpu_accel_off_x = ax_av;
    mpu_accel_off_y = ay_av;
    mpu_accel_off_z = az_av - 16384; // 1g offset for Z axis
    mpu_gyro_off_x = gx_av;
    mpu_gyro_off_y = gy_av;
    mpu_gyro_off_z = gz_av;
  }

  void mpuRead(float &axg, float &ayg, float &azg, float &gx_dps, float &gy_dps, float &gz_dps) {
    int16_t ax,ay,az,gx,gy,gz;
    mpuReadRaw(ax,ay,az,gx,gy,gz);
    
    int32_t axc = (int32_t)ax - mpu_accel_off_x;
    int32_t ayc = (int32_t)ay - mpu_accel_off_y;
    int32_t azc = (int32_t)az - mpu_accel_off_z;
    int32_t gxc = (int32_t)gx - mpu_gyro_off_x;
    int32_t gyc = (int32_t)gy - mpu_gyro_off_y;
    int32_t gzc = (int32_t)gz - mpu_gyro_off_z;
    
    axg = (float)axc / 16384.0f;
    ayg = (float)ayc / 16384.0f;
    azg = (float)azc / 16384.0f;
    gx_dps = (float)gxc / 131.0f;
    gy_dps = (float)gyc / 131.0f;
    gz_dps = (float)gzc / 131.0f;
  }

  void begin() {
    if (inited) return;
    // Initialize MPU6050 (basic init + quick calibration)
    mpuInit();
    mpuCalibrate(150);
    inited = true;
  }

  void update() {
    if (!inited) return;
    updateEmotionsFromIMU();
    updateLivelinessFromIMU();
  }
}}

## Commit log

2025-08-25 Update the AI to be more clean and fast
    [partitions.csv]
2025-08-27 WFI Config
    [DogePet.3mf, partitions.csv]
